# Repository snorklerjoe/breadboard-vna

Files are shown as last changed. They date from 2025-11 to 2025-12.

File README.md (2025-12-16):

# Super VNA

This is a 10MHz, 1-port VNA, built on a breadboard.  
Our design utilizes a Tayloe detector to downconvert the received reflected signal, which is different from conventional VNAs and can be much cheaper in construction. Additionally, we replace the conventionally used directional coupler with a wheatstone resistive bridge, which has been done before in the NanoVNA (a commercially-available hobbyist-grade VNA).

A schematic is available [here](./hardware/SuperVNA/schematic_sheets.pdf).

## Usage

Calibration occurs each time the device is power-cycled.  
Tap anywhere on the touchscreen once the requested standard is connected.  

Afterwards, a white square appears in the upper-right-hand corner of the screen. This button switches between the graph and menu views.  
In the graph view, the graph continuously updates as the device does each sweep.
In the menu view, the insertion loss and phase traces can be turned on and off, and the number of pixels-per-decade ("PPD") can be adjusted to change the graph scaling.

A picture of the device on the breadboard:

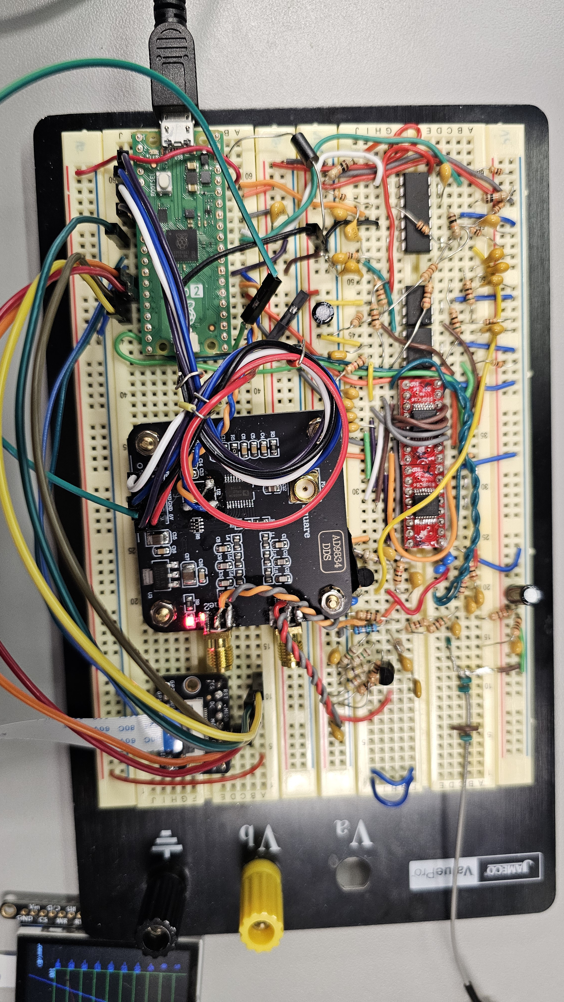
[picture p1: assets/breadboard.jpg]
Image of the device on a breadboard


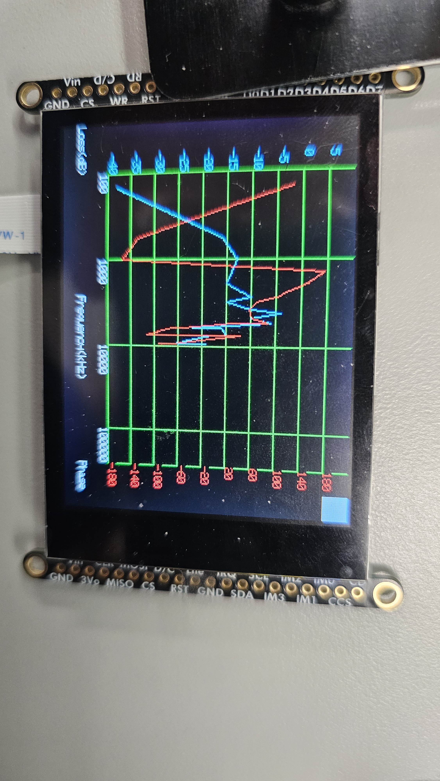
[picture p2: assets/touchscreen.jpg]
Image of the touchscreen


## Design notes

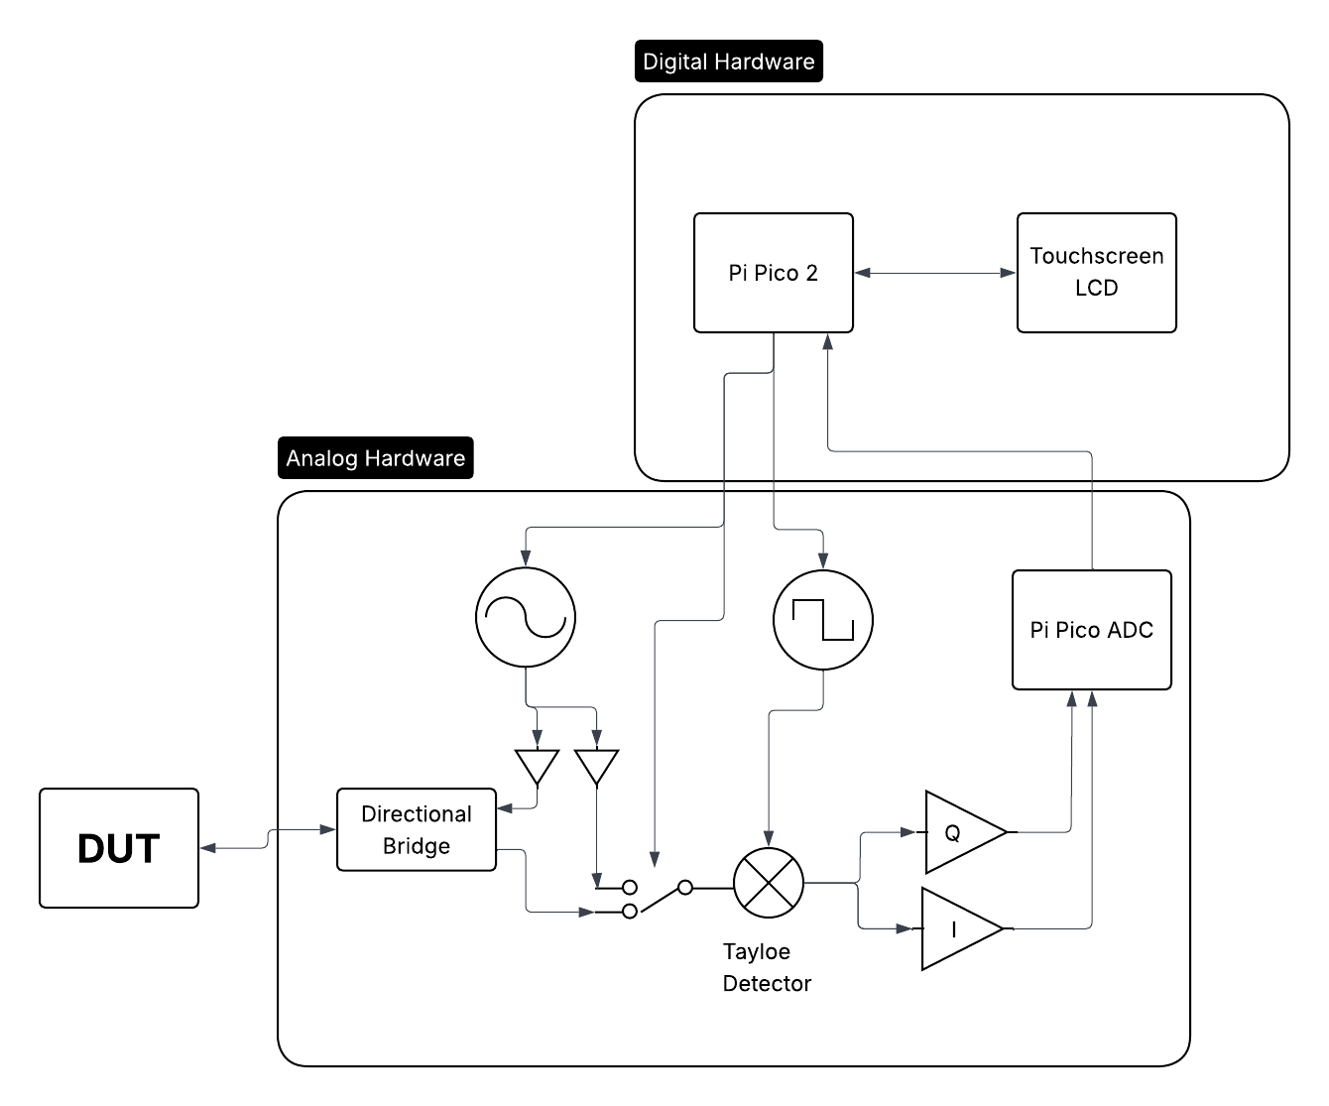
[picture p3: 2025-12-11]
assets/block_diagram.jpg

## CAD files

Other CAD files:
enclosure/LaserCutEnclosure.FCStd

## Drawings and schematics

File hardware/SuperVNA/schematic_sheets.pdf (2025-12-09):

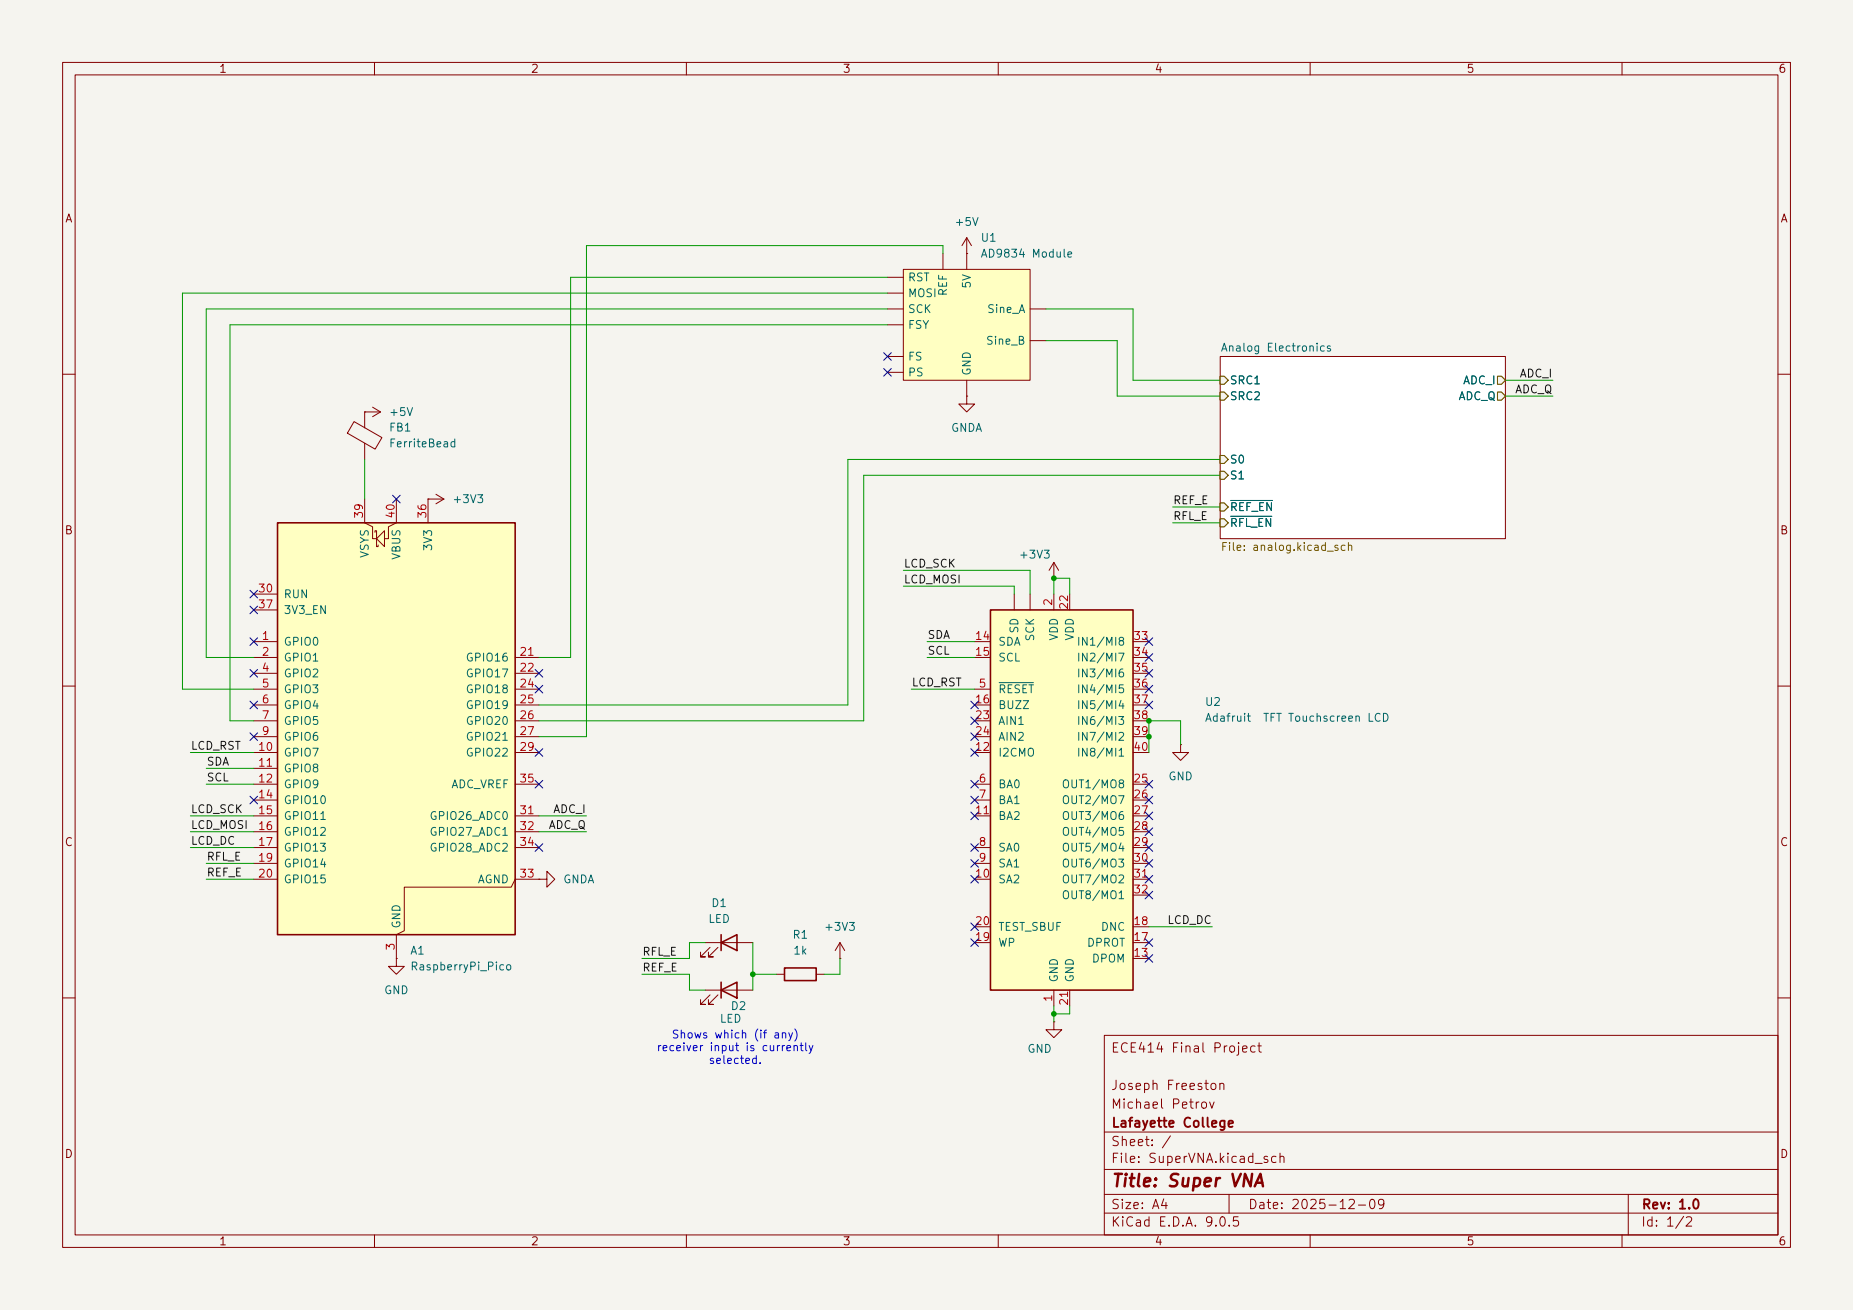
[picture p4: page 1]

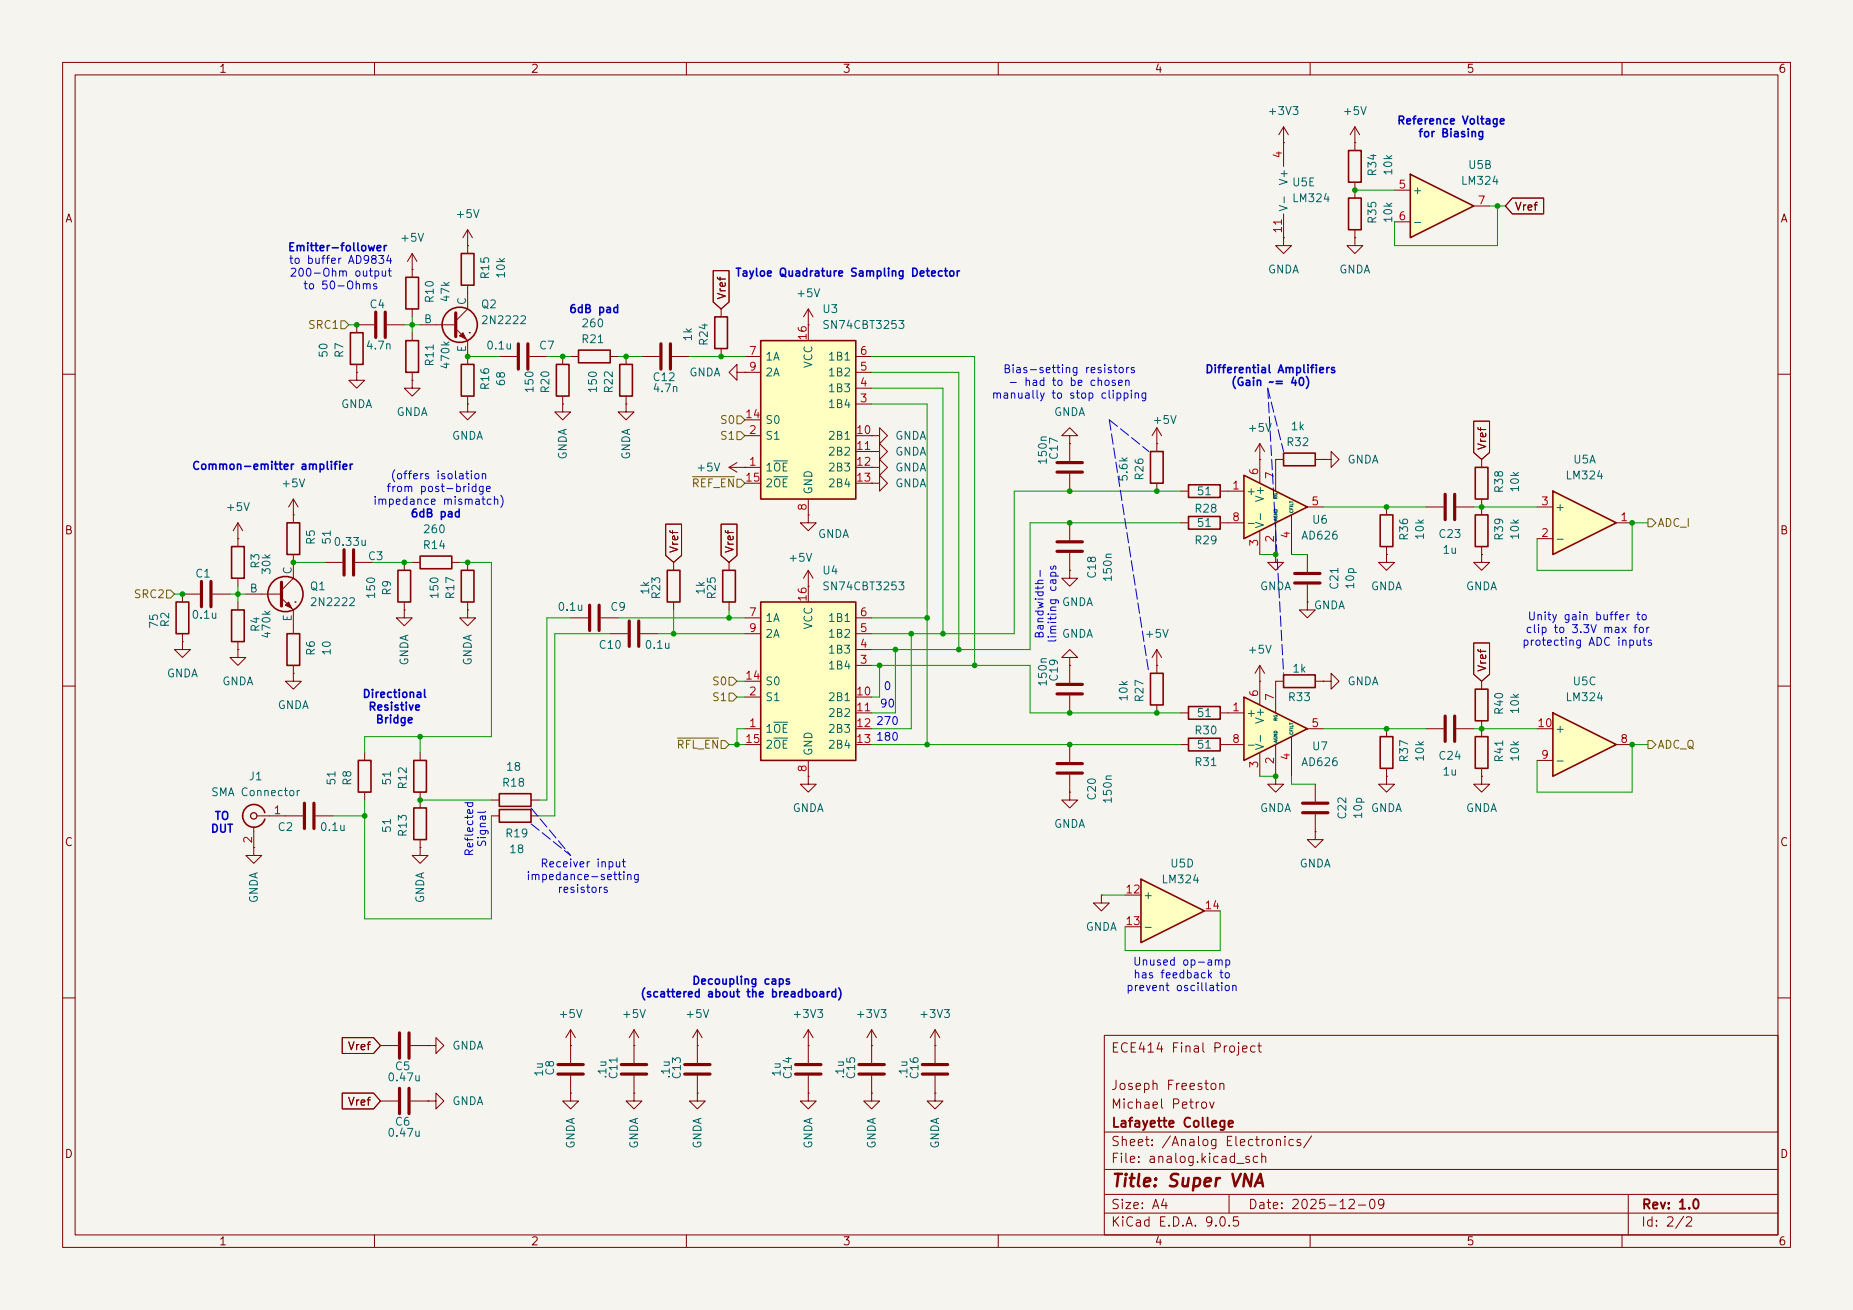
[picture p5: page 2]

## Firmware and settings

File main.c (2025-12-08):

#include <stdio.h>
#include "pico/stdlib.h"
#include "ILI9341.h"
#include "FT6206.h"
#include "hardware/spi.h"
#include "hardware/i2c.h"
#include <math.h>

#include <pico/mutex.h>
#include <pico/multicore.h>
#include "vna.h"
#include "vnasweeps.h"
#include "complex_math.h"


// #define TEST_MODE   // When defined, continuously measures at 1MHz without ui


// Number of measurements to average together, discarding one outlier
const uint meas_avgs = 1;  // For normal measurements
const uint cal_avgs = 2;   // For initial calibration

// Number of points in a measurement
#define num_points 50
// Colors for the graph traces
#define phaseColor 0x00FF
#define lossColor 0xFF00

// Stores the setup of the measurement
vna_meas_setup_t measurement_setup;

// Stores the data from calibration and measurement
vna_meas_t measurement_data;

// Stores the data that actually get graphed
double *graph_frequencies;     // An array (size `num_points`)
double graph_return_loss_dB[num_points];
double graph_phase_deg[num_points];

// Global coordinate buffers
uint16_t a, b;

// TFT Display setup
ili9341_t tft = {
    .spi = spi1,
    .cs  = 13,
    .dc  = 12,
    .rst = 7,
    .mosi = 11,
    .sck = 10
};

// Mutex for data arrays that get graphed
mutex_t data_mutex;
// Tells when new data is available
bool change = false;

// Test function for now...
void test() {
    vna_set_freq(1000);  // 1MHz
    while(1) {
        printf("\n\r");
        vna_meas_point_gamma_raw(1);
    }
}

//For formatting loss coordinate values to our graph
void lossConversion(int *coords, size_t length){
    for(int i = 0; i < length; i++){
        *coords = 4*(*coords + 40);
        coords++;
    }
}

//For formatting phase coordinate values to our graph
void phaseConversion(int *coords, size_t length){
    for(int i = 0; i < length; i++){
        *coords = 0.5*(*coords + 180);
        coords++;
    }
}

// Initialize VNA hardware
void init_vna() {
    // Initialize hardware
    vna_init();

    // Define masurement setup
    measurement_setup = (vna_meas_setup_t){
        // Start (kHz)
        (double) 250,
        // End (kHz)
        (double) 12500,
        // Num Points
        (uint) num_points
    };

    // Initialize measurement data arrays
    measurement_data = vna_meas_init(&measurement_setup);
    
    // Copy pointer to frequencies array
    graph_frequencies = measurement_data.frequencies;
}

// Calibrate
void calibration_routine() {
    // UI: Ask the user to connect a SHORT
    // Wait for them to press a button or press the screen or something
    ili9341_fill_screen(&tft, 0x0000);
    ili9341_box(&tft, 100, 100, 20, 80, 0x0000);
    ili9341_drawString(&tft, 100, 100, "Connect Short  ", 0xFFFF, 0x0000, 2);
    while (1){
        if (ft6206_read_touch(&a, &b)){
            break;
        }
    }

    sleep_ms(100);
    ili9341_drawString(&tft, 100, 150, "Loading...", 0xFFFF, 0x0000, 1);
    vna_sweep_freq(measurement_data, measurement_data.cal_short, cal_avgs);
    ili9341_box(&tft, 150, 100, 100, 100, 0x0000);

    // UI: Ask the user to connect a OPEN
    // Wait for them to press a button or press the screen or something
    ili9341_drawString(&tft, 100, 100, "Connect Open   ", 0xFFFF, 0x0000, 2);
    while (1){
        if (ft6206_read_touch(&a, &b)){
            break;
        }
    }

    sleep_ms(100);
    ili9341_drawString(&tft, 100, 150, "Loading...", 0xFFFF, 0x0000, 1);
    vna_sweep_freq(measurement_data, measurement_data.cal_open, cal_avgs);
    ili9341_box(&tft, 150, 100, 100, 100, 0x0000);


    // UI: Ask the user to connect a LOAD
    // Wait for them to press a button or press the screen or something
    ili9341_drawString(&tft, 100, 100, "Connect Load  ", 0xFFFF, 0x0000, 2);
    while (1){
        if (ft6206_read_touch(&a, &b)){
            break;
        }
    }
    ili9341_drawString(&tft, 100, 150, "Loading...", 0xFFFF, 0x0000, 1);
    vna_sweep_freq(measurement_data, measurement_data.cal_load, cal_avgs);

    // Do calibration 3-term error model maths
    vna_run_cal(measurement_data);
}

// Takes a measurement
void take_measurement() {
    // Take measurement and put it in the measurement_data arrays
    vna_sweep_freq(measurement_data, measurement_data.gammas_uncald, meas_avgs);

    // Apply calibration
    vna_run_correction(measurement_data);

    // Prep data for graphing
    mutex_enter_blocking(&data_mutex);
    for(uint i = 0; i < num_points; i++) {
        // Save the phase angle of the reflection coefficient
        graph_phase_deg[i] = cplx_ang_deg(
            measurement_data.gammas_cald[i]
        );

        // Save the return loss
        graph_return_loss_dB[i] = gamma_to_s11dB(
            measurement_data.gammas_cald[i]
        );
    }
    mutex_exit(&data_mutex);
    
    // Print out Impedance vs. Freq
    // double prevfreq = 0.0;
    // for(uint i = 0; i < num_points; i++) {
    //     double freq = measurement_data.frequencies[i]/1000;
    //     if (freq == prevfreq) continue;

    //     double_cplx_t gamma = cplx_scale(measurement_data.gammas_cald[i], 1.0);
    //     double_cplx_t impedance = cplx_scale(cplx_div(
    //         cplx_add(cplx_unity, gamma),
    //         cplx_sub(cplx_unity, gamma)
    //     ), 50.0);
    //     printf("Freq: %fMHz  \tZ=(%f + j%f)    \n\r", freq, impedance.a, impedance.b);
    //     printf("             \tGamma = %f \t< %f    \n\r", cplx_mag(gamma), cplx_ang_deg(gamma));
    //     prevfreq = freq;
    // }
    // printf("\n\r");
}

// Measurement task to run on core 2
void meas_core_task() {
    while(1) {
        take_measurement();
        change = true;
    }
}

int main() {
    stdio_init_all();
    init_vna();

    // Run test mode if compiled with set
    #ifdef TEST_MODE
    test();
    #endif

    ili9341_init(&tft);
    ft6206_init();

    mutex_init(&data_mutex);  // Initialize mutex for multicore
    
    int yLossCoords[num_points];
    int xCoords[num_points];
    int yPhaseCoords[num_points];
    
    int PPD = 70; //Pixels per decade
    bool LOSS = true; //Display loss
    bool PHASE = true; //Display phase

    bool MENU = true;
    ili9341_fill_screen(&tft, 0x0000);

    // RUN CALIBRATION:
    calibration_routine();

    // Start measurement loop in the background:
    multicore_launch_core1(meas_core_task);

    ili9341_box(&tft, 0, 300, 20, 20, 0x0000);
    while (1){
        if (ft6206_read_touch(&a, &b)){ //Checking if button that switches between Menu and Graph is pushed
            //Not accurate ranges for the box, but makes things easier
            if(a <= 40 && b <= 40){
                MENU = !MENU;
                change = true;
                sleep_ms(100);
            }
        }

        
        if(MENU){ //In Menu screen

            if(change){
                ili9341_fill_screen(&tft, 0x0000);
                ili9341_box(&tft, 0, 300, 20, 20, 0xFFFF);
                ili9341_drawString(&tft, 140, 0, "MENU", 0xFFFF, 0x0000, 2);
                
                ili9341_drawString(&tft, 50, 50, "PPD", 0xFFFF, 0x0000, 2);
                ili9341_drawString(&tft, 150, 50, "TOG", 0xFFFF, 0x0000, 2);

                ili9341_box(&tft, 80, 50, 20, 30, 0x0000);
                ili9341_drawString(&tft, 50, 80, "50", 0xFFFF, 0x0000, 2);
                ili9341_box(&tft, 110, 50, 20, 30, 0x0000);
                ili9341_drawString(&tft, 50, 110, "60", 0xFFFF, 0x0000, 2);
                ili9341_box(&tft, 140, 50, 20, 30, 0x0000);
                ili9341_drawString(&tft, 50, 140, "70", 0xFFFF, 0x0000, 2);
                ili9341_box(&tft, 170, 50, 20, 30, 0x0000);
                ili9341_drawString(&tft, 50, 170, "80", 0xFFFF, 0x0000, 2);
                ili9341_box(&tft, 200, 50, 20, 30, 0x0000);
                ili9341_drawString(&tft, 50, 200, "90", 0xFFFF, 0x0000, 2);

                ili9341_box(&tft, 80, 150, 20, 50, 0x0000);
                ili9341_drawString(&tft, 150, 80, "LOSS", 0xFFFF, 0x0000, 2);
                ili9341_box(&tft, 110, 150, 20, 50, 0x0000);
                ili9341_drawString(&tft, 150, 110, "PHAS", 0xFFFF, 0x0000, 2);
                ili9341_box(&tft, 140, 150, 20, 50, 0x0000);
                ili9341_drawString(&tft, 150, 140, "BOTH", 0xFFFF, 0x0000, 2);
                
                change = false;
            }

            if (ft6206_read_touch(&a, &b)){
                if(b <= 260 && b >= 230){ //Freq buttons
                    if(a >= 80 && a <= 100){
                        for(int i = 0; i < num_points; i++){
                            xCoords[i] = 50*xCoords[i]/PPD;
                        }
                        PPD = 50;
                        ili9341_box(&tft, 80, 50, 20, 30, 0x001F);
                        ili9341_drawString(&tft, 50, 80, "50", 0xFFFF, 0x0000, 2);
                        sleep_ms(100);
                    }
                    else if(a >= 110 && a <= 130){
                        for(int i = 0; i < num_points; i++){
                            xCoords[i] = 60*xCoords[i]/PPD;
                        }
                        PPD = 60;
                        ili9341_box(&tft, 110, 50, 20, 30, 0x001F);
                        ili9341_drawString(&tft, 50, 110, "60", 0xFFFF, 0x0000, 2);
                        sleep_ms(100);
                    }
                    else if(a >= 140 && a <= 160){
                        for(int i = 0; i < num_points; i++){
                            xCoords[i] = 70*xCoords[i]/PPD;
                        }
                        PPD = 70;
                        ili9341_box(&tft, 140, 50, 20, 30, 0x001F);
                        ili9341_drawString(&tft, 50, 140, "70", 0xFFFF, 0x0000, 2);
                        sleep_ms(100);
                    }
                    else if(a >= 170 && a <= 190){
                        for(int i = 0; i < num_points; i++){
                            xCoords[i] = 80*xCoords[i]/PPD;
                        }
                        PPD = 80;
                        ili9341_box(&tft, 170, 50, 20, 30, 0x001F);
                        ili9341_drawString(&tft, 50, 170, "80", 0xFFFF, 0x0000, 2);
                        sleep_ms(100);
                    }
                    else if(a >= 200 && a <= 220){
                        for(int i = 0; i < num_points; i++){
                            xCoords[i] = 90*xCoords[i]/PPD;
                        }
                        PPD = 90;
                        ili9341_box(&tft, 200, 50, 20, 30, 0x001F);
                        ili9341_drawString(&tft, 50, 200, "90", 0xFFFF, 0x0000, 2);
                        sleep_ms(100);
                    }
                }
                else if(b <= 160 && b >= 130){ //Toggle buttons
                    if(a >= 80 && a <= 100){
                        ili9341_box(&tft, 80, 150, 20, 50, 0x001F);
                        ili9341_drawString(&tft, 150, 80, "LOSS", 0xFFFF, 0x0000, 2);
                        LOSS = true;
                        PHASE = false;
                        sleep_ms(100);
                    }
                    else if(a >= 110 && a <= 130){
                        ili9341_box(&tft, 110, 150, 20, 50, 0x001F);
                        ili9341_drawString(&tft, 150, 110, "PHAS", 0xFFFF, 0x0000, 2);
                        LOSS = false;
                        PHASE = true;
                        sleep_ms(100);
                    }
                    else if(a >= 140 && a <= 160){
                        ili9341_box(&tft, 140, 150, 20, 50, 0x001F);
                        ili9341_drawString(&tft, 150, 140, "BOTH", 0xFFFF, 0x0000, 2);
                        LOSS = true;
                        PHASE = true;
                        sleep_ms(100);
                    }
                }
            }
        }

        else{ //In Graph screen
            if(change){
                // Acknowledge change
                change = false;

                // Acquire lock
                mutex_enter_blocking(&data_mutex);

                // Copy data
                for(int i = 0; i < num_points; i++){
                    //x is y
                    yLossCoords[i] = graph_return_loss_dB[i];
                    yPhaseCoords[i] = graph_phase_deg[i];
                    xCoords[i] = PPD*log10(graph_frequencies[i]*1000)-5*PPD;
                }

                // Release lock
                mutex_exit(&data_mutex);

                lossConversion(yLossCoords, num_points);
                phaseConversion(yPhaseCoords, num_points);

                ili9341_fill_screen(&tft, 0x0000);
                ili9341_line(&tft, 200, 40, 200, 280, 0x07E0);
                ili9341_line(&tft, 200, 40, 0, 40, 0x07E0);
                ili9341_line(&tft, 200, 280, 0, 280, 0x07E0); //Make sure this works
                char str[5];
                int j = 40;
                for(int i = 5; j < 280; i++){//changed from 320
                    int temp = pow(10,i)/1000;
                    sprintf(str, "%d", temp);
                    ili9341_drawString(&tft, j, 201, str, 0xFFFF, 0x0000, 1);
                    ili9341_line(&tft, 200, j, 0, j, 0x07E0);
                    j = j + PPD;
                }

                for(int i = -40; i < 6; i = i + 5){
                    sprintf(str, "%d", i);
                    ili9341_drawString(&tft, 25, 193 - 4*(40+i), str, lossColor, 0x0000, 1);
                    ili9341_line(&tft, 200 - 4*(40+i), 40, 200 - 4*(40+i), 280, 0x07E0);
                }

                for(int i = -180; i < 200; i = i + 40){
                    sprintf(str, "%d", i);
                    ili9341_drawString(&tft, 280, 193 - 0.5*(180+i), str, phaseColor, 0x0000, 1);
                }
                if(LOSS) ili9341_drawOnCartGraph(&tft, yLossCoords, xCoords, sizeof(xCoords)/sizeof(xCoords[0]), lossColor);
                if(PHASE) ili9341_drawOnCartGraph(&tft, yPhaseCoords, xCoords, sizeof(xCoords)/sizeof(xCoords[0]), phaseColor);

                

                ili9341_drawString(&tft, 140, 220, "Frequency(kHz)", 0xFFFF, 0x0000, 1);
                ili9341_drawString(&tft, 0, 220, "Loss(dB)", 0xFFFF, 0x0000, 1);
                ili9341_drawString(&tft, 280, 220, "Phase", 0xFFFF, 0x0000, 1);

                ili9341_box(&tft, 0, 300, 20, 20, 0xFFFF);
                change = false;
            }
        }
    }
}

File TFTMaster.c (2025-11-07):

//NOTE: MOVED THIS AND HEADER OVER FROM LAB5, NOT SURE IF IT WILL WORK FOR OUR BOARD
//HERE IS WHAT THE PAGE FOR OUR BOARD DIRECTED ME TO FOR INTERFACING LIBRARY FOR CAPACITIVE TOUCHSCREEN:
//https://github.com/adafruit/TFTLCD-Library/blob/master/Adafruit_TFTLCD.h
/* Code rewritten from Adafruit Arduino library for the TFT
 *  by Syed Tahmid Mahbub
 * The TFT itself is Adafruit product 1480
 * Included below is the text header from the original Adafruit library
 *  followed by the code
 */

/*
This is the core graphics library for all our displays, providing a common
set of graphics primitives (points, lines, circles, etc.).  It needs to be
paired with a hardware-specific library for each display device we carry
(to handle the lower-level functions).

Adafruit invests time and resources providing this open source code, please
support Adafruit & open-source hardware by purchasing products from Adafruit!

Copyright (c) 2013 Adafruit Industries.  All rights reserved.

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
- Redistributions of source code must retain the above copyright notice,
  this list of conditions and the following disclaimer.
- Redistributions in binary form must reproduce the above copyright notice,
  this list of conditions and the following disclaimer in the documentation
  and/or other materials provided with the distribution.

THIS SOFTWARE IS PROVIDED BY THE COPYRIGHT HOLDERS AND CONTRIBUTORS "AS IS"
AND ANY EXPRESS OR IMPLIED WARRANTIES, INCLUDING, BUT NOT LIMITED TO, THE
IMPLIED WARRANTIES OF MERCHANTABILITY AND FITNESS FOR A PARTICULAR PURPOSE
ARE DISCLAIMED. IN NO EVENT SHALL THE COPYRIGHT HOLDER OR CONTRIBUTORS BE
LIABLE FOR ANY DIRECT, INDIRECT, INCIDENTAL, SPECIAL, EXEMPLARY, OR
CONSEQUENTIAL DAMAGES (INCLUDING, BUT NOT LIMITED TO, PROCUREMENT OF
SUBSTITUTE GOODS OR SERVICES; LOSS OF USE, DATA, OR PROFITS; OR BUSINESS
INTERRUPTION) HOWEVER CAUSED AND ON ANY THEORY OF LIABILITY, WHETHER IN
CONTRACT, STRICT LIABILITY, OR TORT (INCLUDING NEGLIGENCE OR OTHERWISE)
ARISING IN ANY WAY OUT OF THE USE OF THIS SOFTWARE, EVEN IF ADVISED OF THE
POSSIBILITY OF SUCH DAMAGE.
*/

/**
 * Parth Sarthi Sharma (pss242@cornell.edu)
 * 
 *
 * HARDWARE CONNECTIONS
 *  - GPIO 18 ---> TFT Chip Select
 *  - GPIO 19 ---> TFT MOSI
 *  - GPIO 17 ---> TFT SCK
 *  - GPIO 16 ---> TFT D/C
 *  - GPIO 20 ---> TFT RST
 *
 * RESOURCES USED
 *  - PIO state machines 0 on PIO instance 0
 *
 * NOTE
 *  - This is a translation of the display primitives
 *    for the PIC32 written by Bruce Land and students
 *	  with an added bitmaps function.
 *
 */

#include <stdio.h>
#include <stdlib.h>
#include "pico/stdlib.h"
#include "hardware/pio.h"
#include "hardware/irq.h"
#include "SPIPIO.pio.h" //Our assembled program
#include "TFTMaster.h" //Header file
#include "glcdfont.c" //Font file

#define pgm_read_byte(addr) (*(const unsigned char *)(addr)) //Read byte at the address

#define NOP asm volatile("nop") //A single no-operation
#define wait8 NOP;NOP;NOP;NOP;NOP;NOP;NOP;NOP;NOP;NOP;NOP;NOP;NOP;NOP;NOP;NOP;NOP;NOP;NOP;NOP;NOP;NOP;NOP;NOP;NOP;NOP;NOP;NOP;NOP;NOP;NOP;NOP; //NOPs for drawing pixels
#define wait16 wait8 wait8 //NOPs for drawing pixels

unsigned short _width, _height; //Width and height of the TFT
unsigned short cursor_y, cursor_x, textsize, textcolor, textbgcolor, wrap, rotation;

typedef struct pio_spi_inst{ //PIO SPI struct 
    PIO pio; //The PIO
    uint sm; //State machine
    uint cs_pin; //Chip select
} pio_spi_inst_t;

PIO pio = pio0; //Identifier for the first (PIO 0) hardware PIO instance
uint sm = 0; //The state machine 
	
pio_spi_inst_t spi = { //The SPI instance
	.pio = pio0,
	.sm = 0,
	.cs_pin = CS
};

uint offset; //Offset for the program to load

volatile char flag = 1; //flag to mark completion of an SPI transaction

void pioPinHandler(){ //The PIO interrupt handler
	pio_interrupt_clear(pio0, 0); //Clear a particular PIO interrupt
	flag = 0; //Clear the flag
}

//Function to intialize all the hardware associated with the TFT
void tft_init_hw(void){
	_width = ILI9340_TFTWIDTH;
	_height = ILI9340_TFTHEIGHT;
  
	gpio_init(CS); //Initialize the CS pin as GPIO 
    gpio_set_dir(CS, GPIO_OUT); //Set the pin direction as output
    gpio_put(CS, 1); //Drive CS high
	
	gpio_init(RST); //Initialize the RST pin as GPIO 
	gpio_set_dir(RST, GPIO_OUT); //Set the pin direction as output
	
	gpio_init(DC); //Initialize the DC pin as GPIO
	gpio_set_dir(DC, GPIO_OUT); //Set the pin direction as output
	
	offset = pio_add_program(spi.pio, &spi_cpha0_cs_program); //Attempt to load the program
    pio_spi_cs_init(spi.pio, spi.sm, offset, 8, 1, false, false, SCK, MOSI); //Initialize the SPI program
	pio_interrupt_clear(spi.pio, 0); //Clear a particular PIO interrupt
    pio_set_irq0_source_enabled(spi.pio, PIO_INTR_SM0_LSB, true); //Enable/Disable a single source on a PIO's IRQ 0
	irq_set_exclusive_handler(PIO0_IRQ_0, pioPinHandler); //Set an exclusive interrupt handler for an interrupt on the executing core
	irq_set_enabled(PIO0_IRQ_0, true); //Enable or disable a specific interrupt on the executing core
	sleep_ms(500); //Sleep for 500ms
}

static inline void _rst_low(){ //Function to set the RST pin low
	gpio_put(RST, 0);
}

static inline void _rst_high(){ //Function to set the RST pin high
	gpio_put(RST, 1);
}

static inline void _dc_low(){ //Function to set the RST pin low
	gpio_put(DC, 0);
}

static inline void _dc_high(){ //Function to set the DC pin high
	gpio_put(DC, 1);
}

static inline void _cs_low(){ //Function to set the RST pin low
	gpio_put(CS, 0);
}

static inline void _cs_high(){ //Function to set the CS pin high
	gpio_put(CS, 1);
}

//Function to transmit a word to the SPI PIO
void __time_critical_func(pio_spi_write8_blocking)(const pio_spi_inst_t *spi, const uint8_t *src, size_t len){
    size_t tx_remain = len;
    io_rw_8 *txfifo = (io_rw_8 *) &spi->pio->txf[spi->sm];
    while (tx_remain){
        if (tx_remain && !pio_sm_is_tx_fifo_full(spi->pio, spi->sm)){
            *txfifo = *src++;
            --tx_remain;
        }
    }
}


void tft_spiwrite8(unsigned char c) { //Write 8 bits to the PIO
	pio_spi_write8_blocking(&spi, &c, 1);
}

void tft_spiwrite16(unsigned short c) { //Write 16 bits to the PIO
	uint8_t data = (uint8_t) (c >> 8);
	pio_spi_write8_blocking(&spi, &data, 1); //Send lower 8 bits
	while(flag); //Wait for the transaction to complete
	flag = 1;
	data = (uint8_t) (c & 0xFF);
	pio_spi_write8_blocking(&spi, &data, 1); //Send upper 8 bits
}

void tft_writecommand(unsigned char c) { //Send a command to the TFT screen
    _dc_low();
	_cs_low();
    tft_spiwrite8(c);
	while(flag);
	flag = 1;
	_cs_high();
}

void tft_writedata(unsigned char c) { //Send 8-bit data to the TFT screen
    _dc_high();
	_cs_low();
    tft_spiwrite8(c);
	while(flag);
	flag = 1;
	_cs_high();
}

void tft_writedata16(unsigned short c) { //Send 16-bit data to the TFT screen
    _dc_high();
	_cs_low();
    tft_spiwrite16(c);
	while(flag);
	flag = 1;
	_cs_high();
}
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

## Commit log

2025-11-03 Adding TFTMaster from lab5, might work for this board
2025-11-12 Removed debug printfs, cleaned up
2025-11-14 AD9834 works from pi pico reference
2025-11-16 Trying to get the LCD to work, no more software problems but there are either problems with hardware or I need a different library.
    [TFTMaster.c, main.c]
2025-11-21 Added KiCAD schematic of current breadboard state
    [SuperVNA.kicad_pcb, SuperVNA.kicad_sch]
2025-11-28 deal with the actual frequency used
    [SuperVNA.kicad_sch]
2025-12-03 Reduced number of samples
2025-12-03 Fixed case-sensitive filenames
2025-12-03 Reduced number of averages, and filter taps for faster measurement
2025-12-03 Fixed a text drawing error
    [main.c]
2025-12-04 Digital downconversion not fully working (only works for short)
    [adc_sampling.c, adc_sampling.h, main.c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]
2025-12-05 Current state
2025-12-07 Made ad9834 accumulator reset more consistent
    [vna.c]
2025-12-07 Skip duplicate frequency points
    [main.c]
2025-12-07 X and Y are swapped?
    [ILI9341.c]
2025-12-08 Improved some phase drift issues
    [receiver.c, vna.c]
2025-12-08 Enclosure design
    [LaserCutEnclosure.FCStd]
2025-12-08 Removed some print statements from testing
2025-12-09 Updated schematic
    [SuperVNA.kicad_sch, analog.kicad_sch]
2025-12-16 Removed copy of pico sdk from codebase
2025-12-16 Add usage section to README
    Added usage instructions for device calibration and operation.
